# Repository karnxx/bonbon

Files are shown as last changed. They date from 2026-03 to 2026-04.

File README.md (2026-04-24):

# BONBON
### Animatronic from FNAF(Five Nights At Freddy's: Sister Localtion). This is basically a puppet of another animatronic, funtime freddy. so this animatronic features a 3dof head, eyes with eyelids, a mouth, and movable ears, 3 dof delta spine, 2 dof arms with 2 dof elbows, and the torso is indipendent, which means it can also move on its own. and the animatronic exos were taken from [@VomitedThoughts'](https://www.thingiverse.com/VomitedThoughts/designs) [BonBon Animatronic NHI](https://www.thingiverse.com/thing:7190069), huge thx to him! Eye mechs inspired from [Will Cogley's](https://www.youtube.com/@WillCogley) vid [How to Make a Compact Animatronic Eye Mechanism with 3D Printing and Arduino](https://www.youtube.com/watch?v=ihXxbQefl1c&list=WL&index=4&t=775s).

## [TUTORIAL](https://docs.google.com/presentation/d/1Cw9k8dLjZv4EjV3Pf7_rws1tL0UiAv238A7aoDvE18U/edit?usp=sharing)
- so i have a tutorial which is low qual but gets the job done.
- i will be making an assemble tutorial vid when i get the chance to make this.

## [BOM](https://docs.google.com/spreadsheets/d/1VHbBl1pK4IkEiJHbse9l7TyNy_vx4ArTAp4to9fVv3g/edit?usp=sharing)
- Google sheets, ive alr included the parts i have, and whats most convinient for me rn - the psu, u can use any power around 5-6v, with 13-15 amps.
  - 11 × SG90 → ~0.25A peak each → ~2.75A
  - 5 × MG90S → ~0.7A peak each → ~3.5A
  - 3 × MG995 → ~2.5A peak each → ~7.5A
  
 
    
## [CAD](https://gmail4855044.autodesk360.com/g/shares/SH90d2dQT28d5b602811fb614439d378a375)
- Cadded on fusion360, which is a great design tool. i also have included the timelapses of me designing bonbon in my journal.
- Ive also added clearances, and you do need inserts for this project.








## ELECTRICALS
- heres the wiring diagram
- im gonna be using an rpi pico for 16 of the servos, then the 3 mg995 ill be using a breadboard.
Untitled Diagram drawio

## CODE
- this is meant to be up to the user, so u can do wtver u want to. i reccomend using bottango or if u want u can rc it.

# NO AI WAS USED

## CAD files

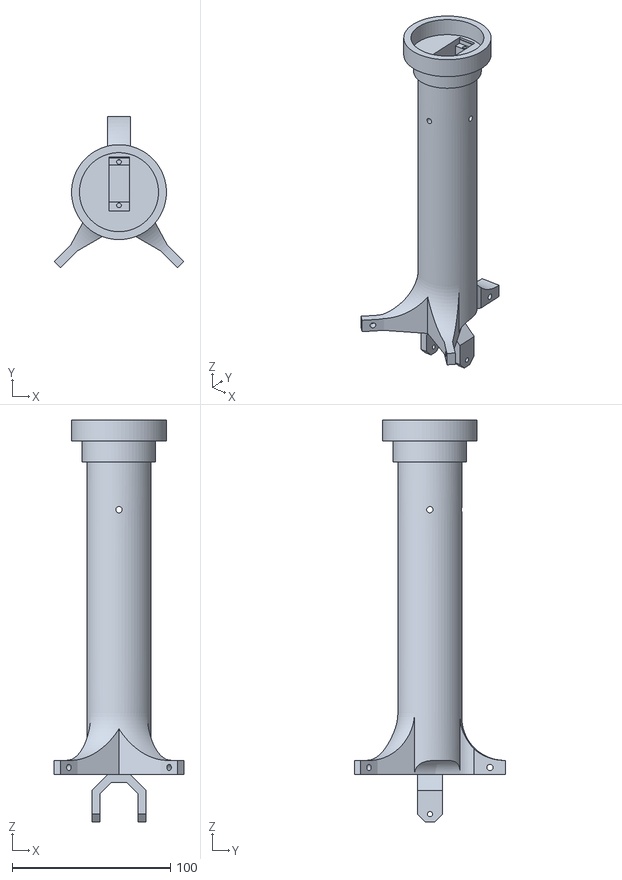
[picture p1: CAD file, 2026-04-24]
cad/printed parts/stls/1xspinewhole.stl
82.0 x 95.8 x 254.2

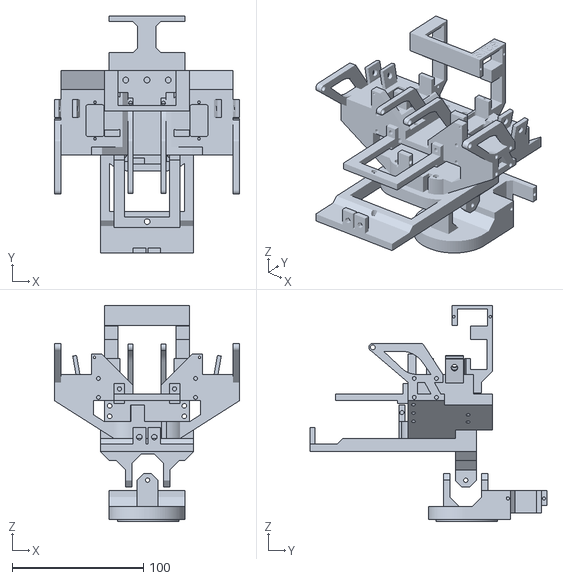
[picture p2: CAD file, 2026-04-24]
cad/printed parts/stls/1xhead.stl
141.1 x 180.6 x 164.6

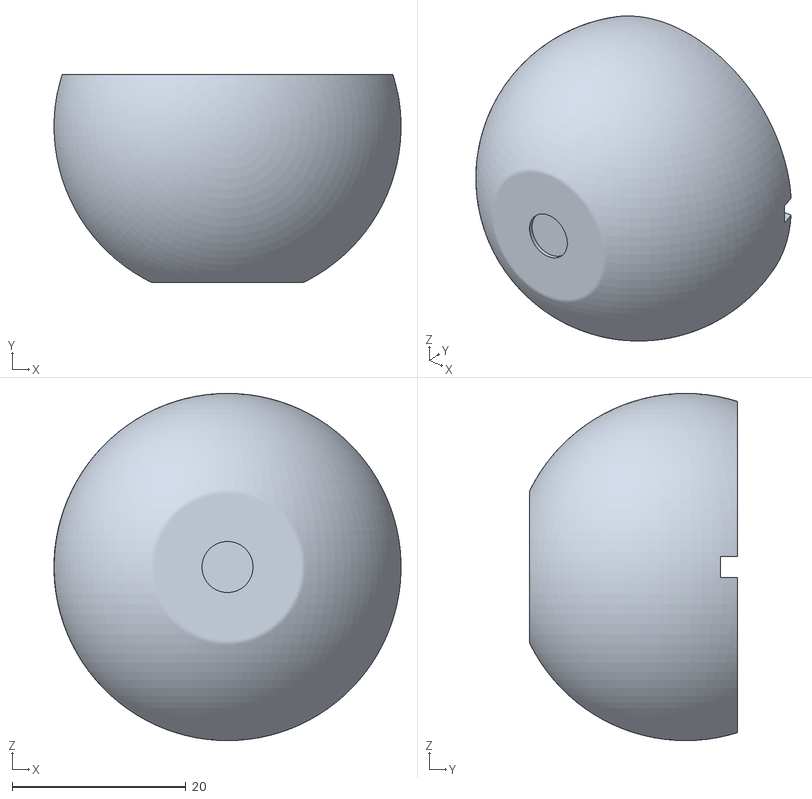
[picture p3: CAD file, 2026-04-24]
cad/printed parts/stls/2xeye.stl
40.0 x 24.0 x 40.0

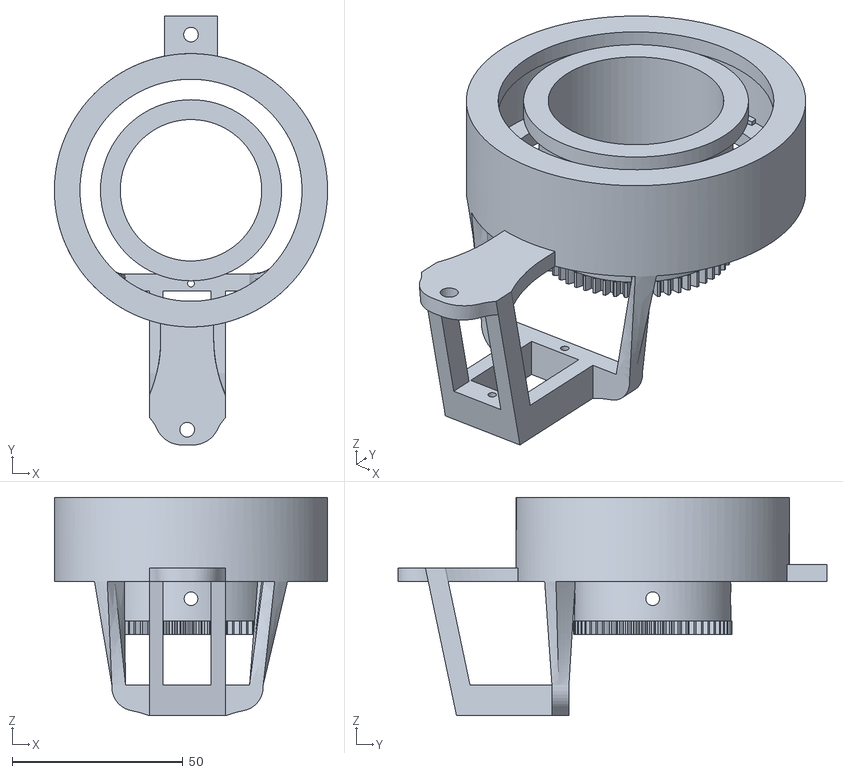
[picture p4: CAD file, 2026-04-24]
cad/printed parts/stls/1xspineconnectorandtorsotospine.stl
80.0 x 125.6 x 63.9

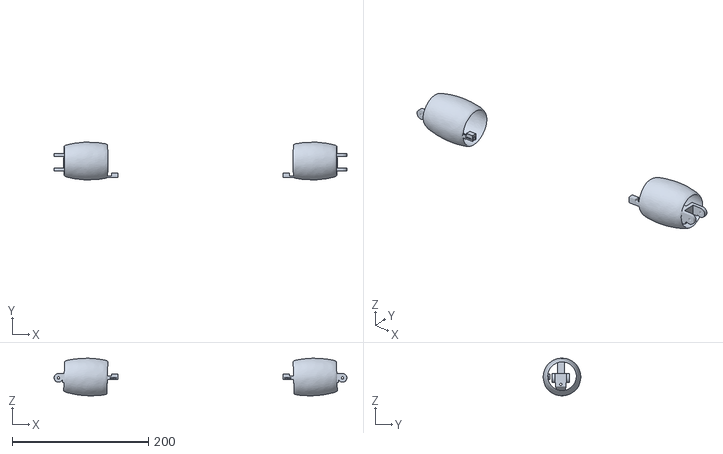
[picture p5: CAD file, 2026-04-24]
cad/printed parts/stls/1xbothforearms.stl
429.9 x 55.3 x 55.1

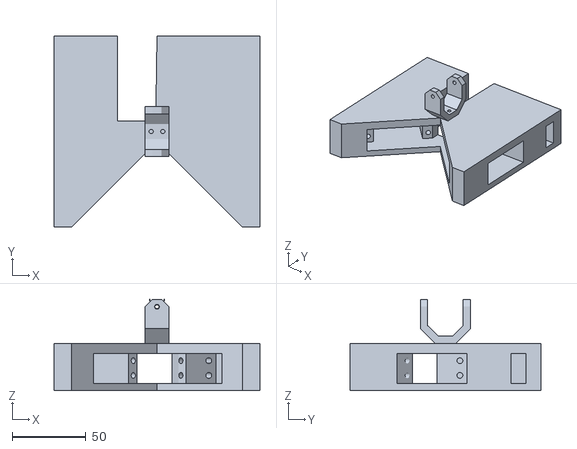
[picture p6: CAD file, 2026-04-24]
cad/printed parts/stls/1xspinebase.stl
140.0 x 130.0 x 62.1

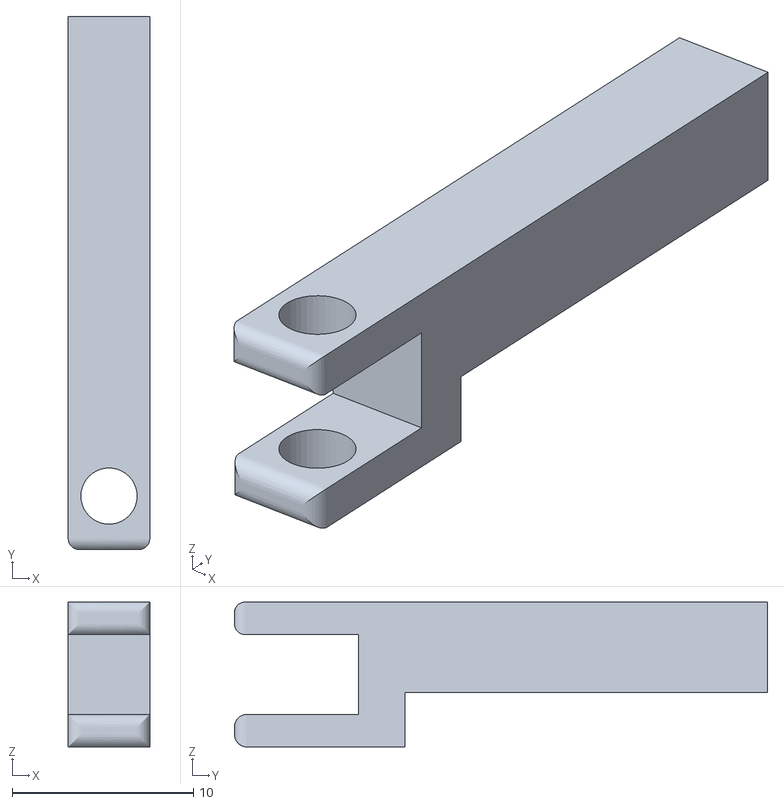
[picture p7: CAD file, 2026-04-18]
cad/printed parts/stls/2xanchoreye.stl
4.50 x 29.4 x 8.00

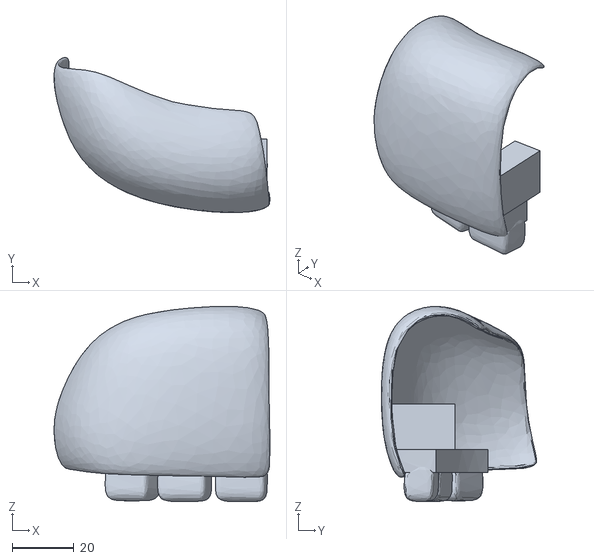
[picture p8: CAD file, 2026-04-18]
cad/printed parts/stls/1xsnoutr.stl
70.2 x 50.5 x 63.5

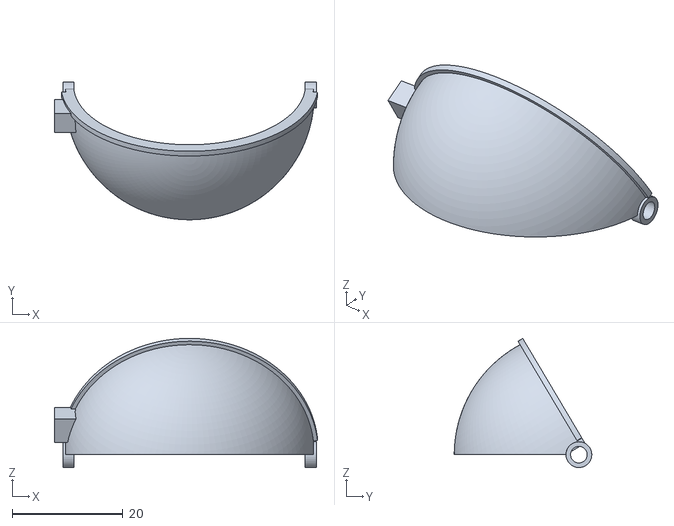
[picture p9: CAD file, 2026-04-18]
cad/printed parts/stls/1xdownlid1.stl
47.4 x 24.8 x 23.3

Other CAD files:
cad/printed parts/stps/shoulders.step
cad/printed parts/stps/forarms.step
cad/printed parts/stps/uptilttoadapter.step
cad/printed parts/stps/uplid1.step
cad/printed parts/stps/snoutl.step
cad/printed parts/stps/spinebase.step
cad/printed parts/stps/torso.step
cad/printed parts/stps/middlerotationpart.step
cad/printed parts/stps/downlidcontroller.step
cad/printed parts/stls/1xbothhands.stl
cad/printed parts/stls/1xbothshoulders.stl
cad/printed parts/stls/1xdownlid2.stl
cad/printed parts/stls/1xdownlidcontroller.stl
cad/printed parts/stls/1xjaw.stl
cad/printed parts/stls/1xjawshaft.stl
cad/printed parts/stls/1xskull.stl
cad/printed parts/stls/1xsnoutl.stl
cad/printed parts/stls/1xtorso.stl
cad/printed parts/stls/1xtorsogear.stl
cad/printed parts/stls/1xuplid1.stl
cad/printed parts/stls/1xuplid2.stl
cad/printed parts/stls/1xuplidcontroller.stl
cad/printed parts/stls/2xcardaninner.stl
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

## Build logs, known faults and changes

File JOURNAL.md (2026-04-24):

---
title: "Project BonBon"
author: "karnxx"
description: "i will attempt at making a bonbon animatronic."
created_at: "2026-3-21"
---

# March 20 2026: Started making the eyeball
- so today i started making the eyeball, since im gonna make the eye system, then the mouth and then ears, then neck and etc. the eyeball is pretty simple, its smtn like [this](https://youtube.com). so i have to custom design the eye and the adapter. this system is very effective, and compact. 

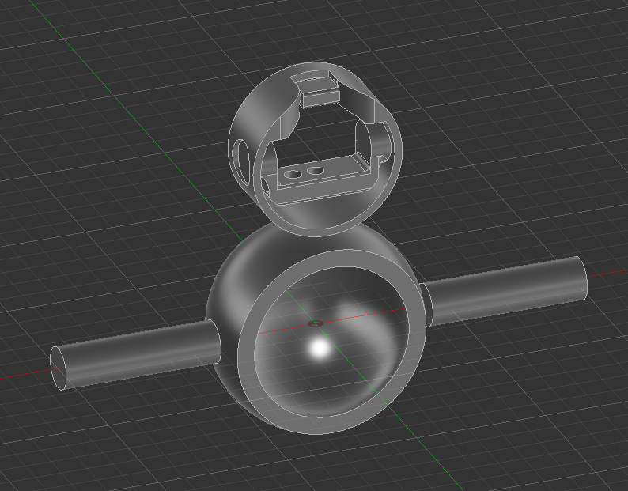
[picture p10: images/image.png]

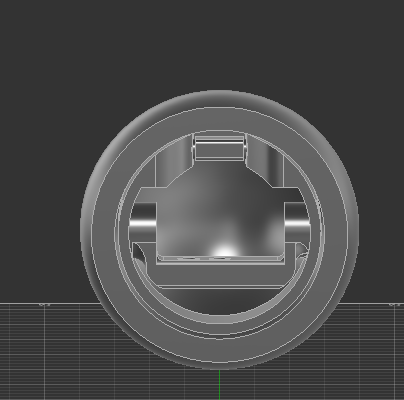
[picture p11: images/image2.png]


https://lapse.hackclub.com/timelapse/bPD6VYQ9OHWk \
https://lapse.hackclub.com/timelapse/R3avVUUkZ5Qu \
**Total time spent: 45 mins**

# March 21, 2026: Made eyeball snapfit.
- so i tried to make the eyeball snapfit. ill have to print them now. so ill print and then check the results.
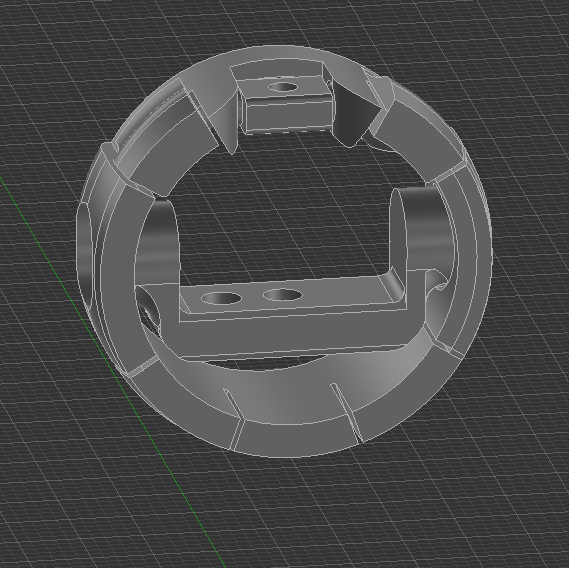
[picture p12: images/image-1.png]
 \
- after this ill ahve to make the main system, ill add joitns in fusion to make it more understandable.

### 9:43 pm

- so i made the things that go to servo. and i also made the fusion joint. i think ima have some problem with the fixed thng at the middle and the moving part right next to it, idk. and lol just as im writing this the print finished, lemme go check. so thrs alotta issues.. so first of all the up thingey is hard to get in, and the thing that supports it is very brittle. then the main adapter is hard to get in as well, and the other part in the adapter is very loose. im so bad at designing lol. ill fix these rn.
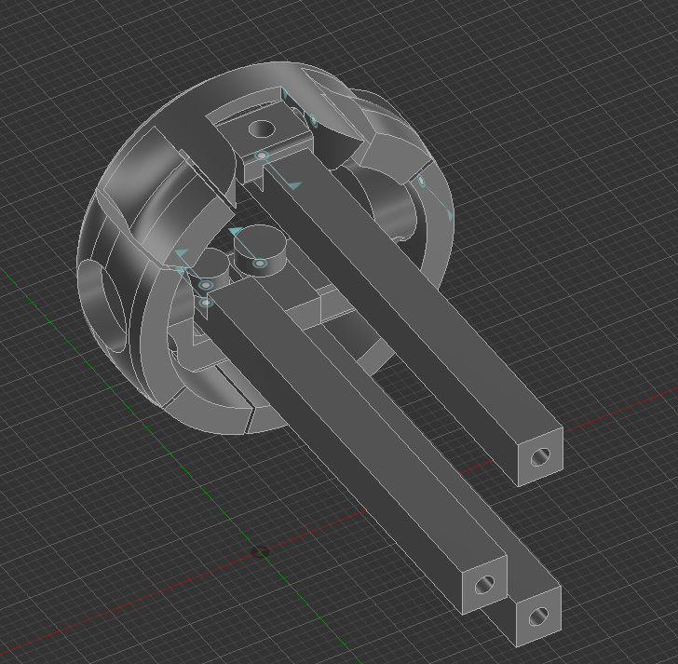
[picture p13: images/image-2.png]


https://lapse.hackclub.com/timelapse/Nn3NmJtqSQf6 \
https://lapse.hackclub.com/timelapse/R2DGub7P9Jni \
**Total time spent: 75 mins**

# March 22 2026: Remade the socket thing for eyeball
- the earlier design  didnt really work out, so i remade it and i printed a test.. which actually worked11!!
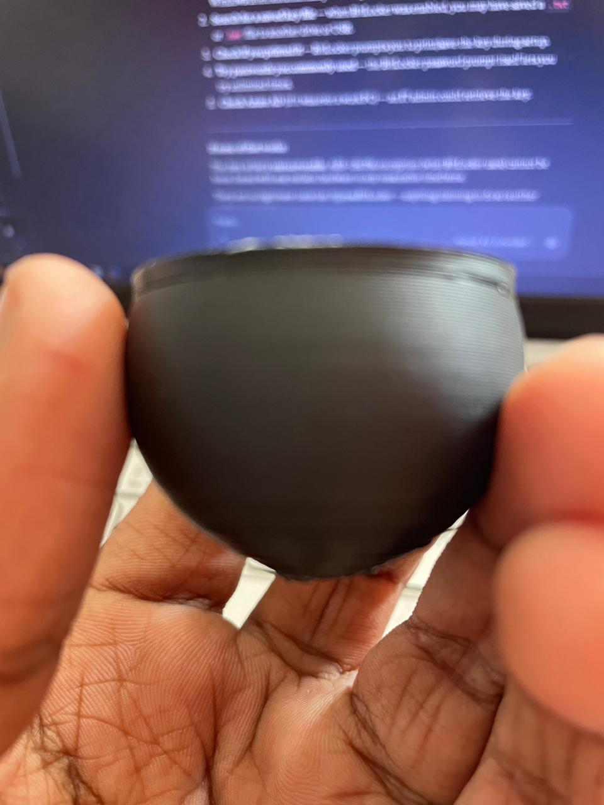
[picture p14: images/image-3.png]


- after that i designed so everything wud be able to fit on this. i also added this lip layer thing so that it wudnt be able to rotate freely in the sphere, and also added notches so it wudnt be rotating there. im gonna be super gluing this also, instead of relying on the joint. also addesd some space between the circle snap thing.

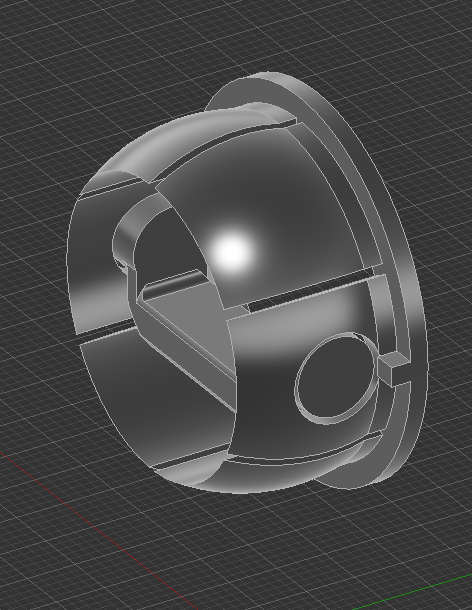
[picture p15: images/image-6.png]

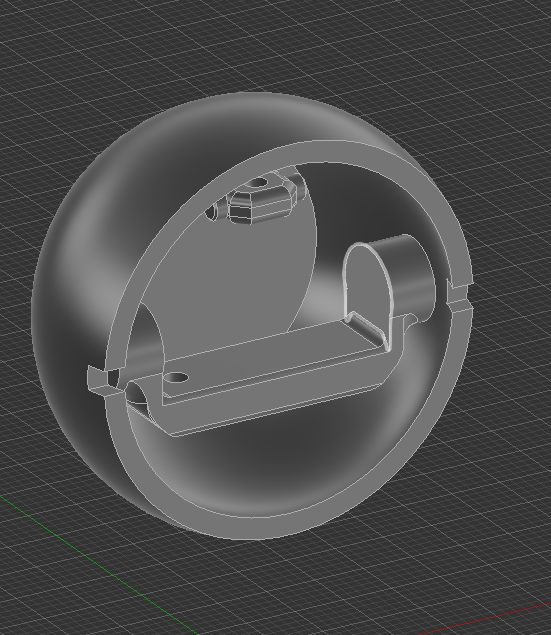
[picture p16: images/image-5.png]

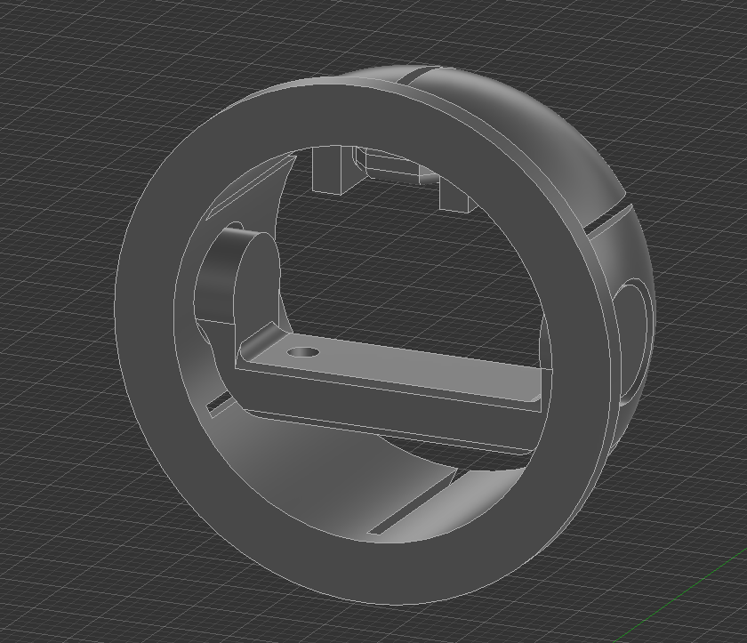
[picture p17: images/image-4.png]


- now ill set it to print and update the results here
- ok so it fits nice, and is easy to remove and all. then uhh themiddle part just needs to be sanded and the upper part is hard to put in, so ill have to fix that. shud be rlly quick, i dont think i need to record lapse.
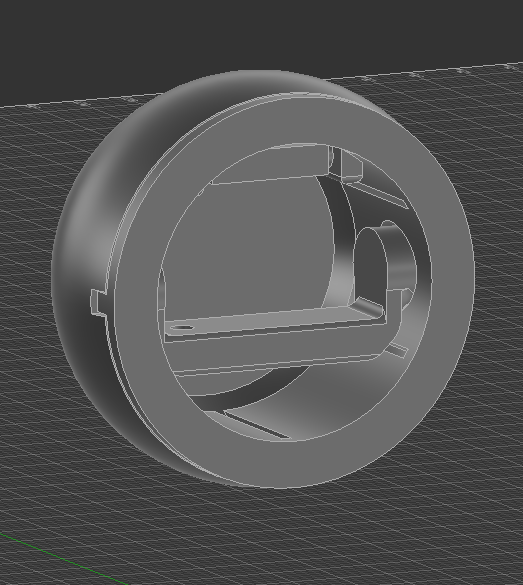
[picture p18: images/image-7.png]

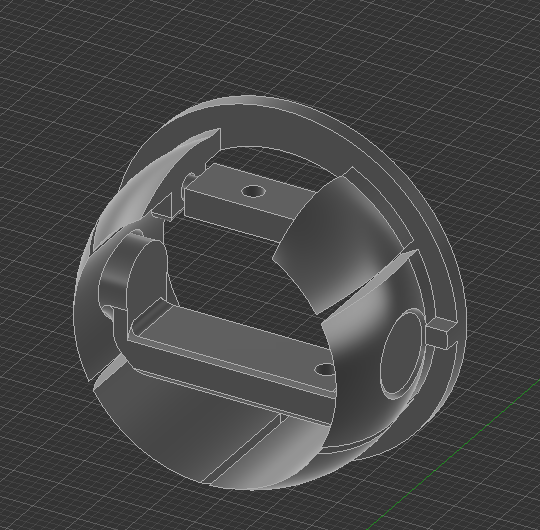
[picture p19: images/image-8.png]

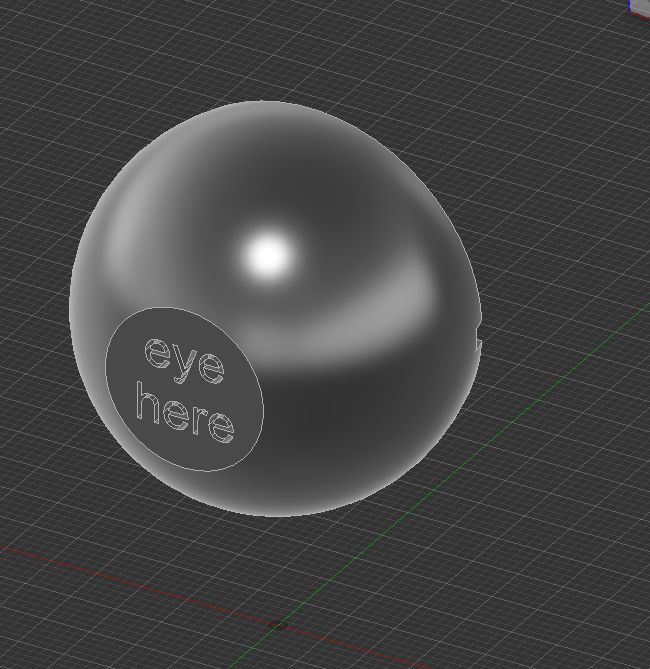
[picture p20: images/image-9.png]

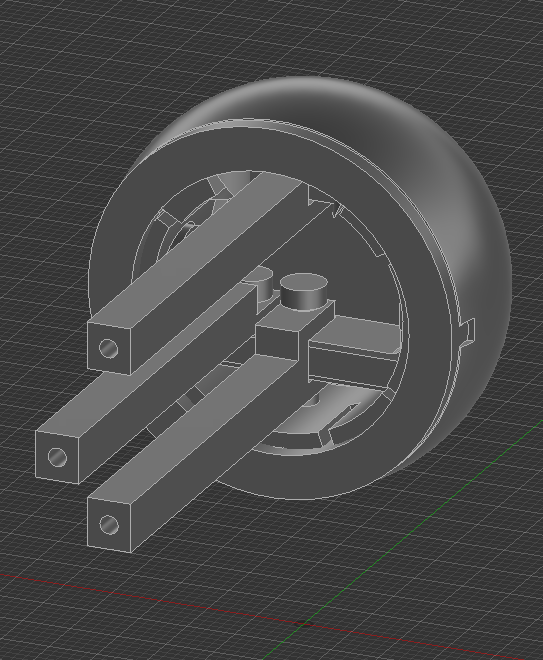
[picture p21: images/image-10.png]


- aight so i printed the new set and i think it came out rlly well. it just needs a bit sanding and a few more tweaks.

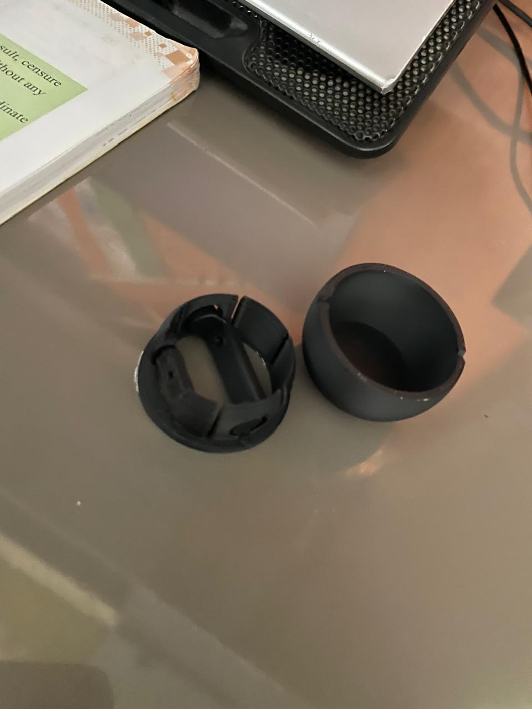
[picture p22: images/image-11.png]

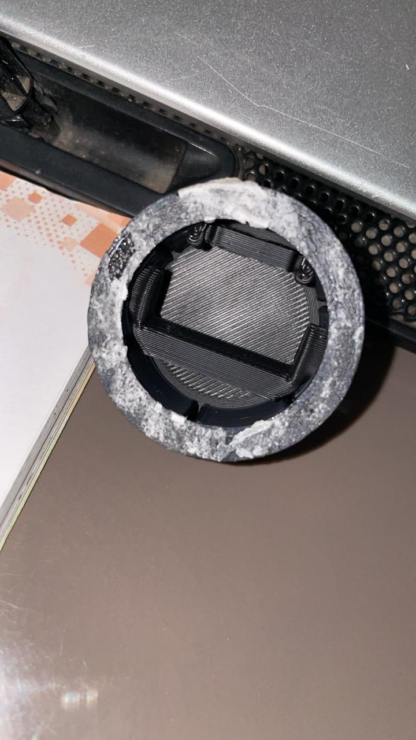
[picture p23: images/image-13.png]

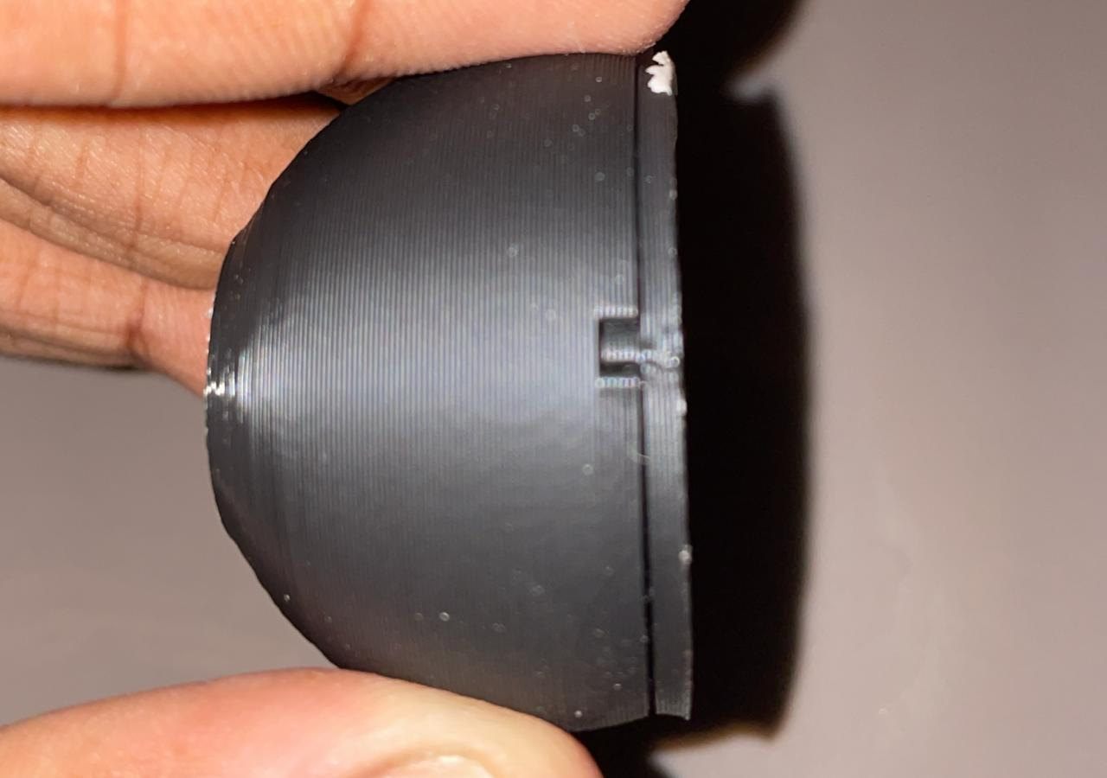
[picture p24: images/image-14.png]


https://lapse.hackclub.com/timelapse/miGNqXrjUI7L \
https://lapse.hackclub.com/timelapse/nTVNja44oHZ4 \
**Total time spent: 30 mins**

# March 23 2026: made eyelids and the main housing.
- today i made the eyelids. they follow a rlly simple system. as you can see, the top eyelids will be controlled by 1 servo while the other two by another. so they connect togehter in the middle area
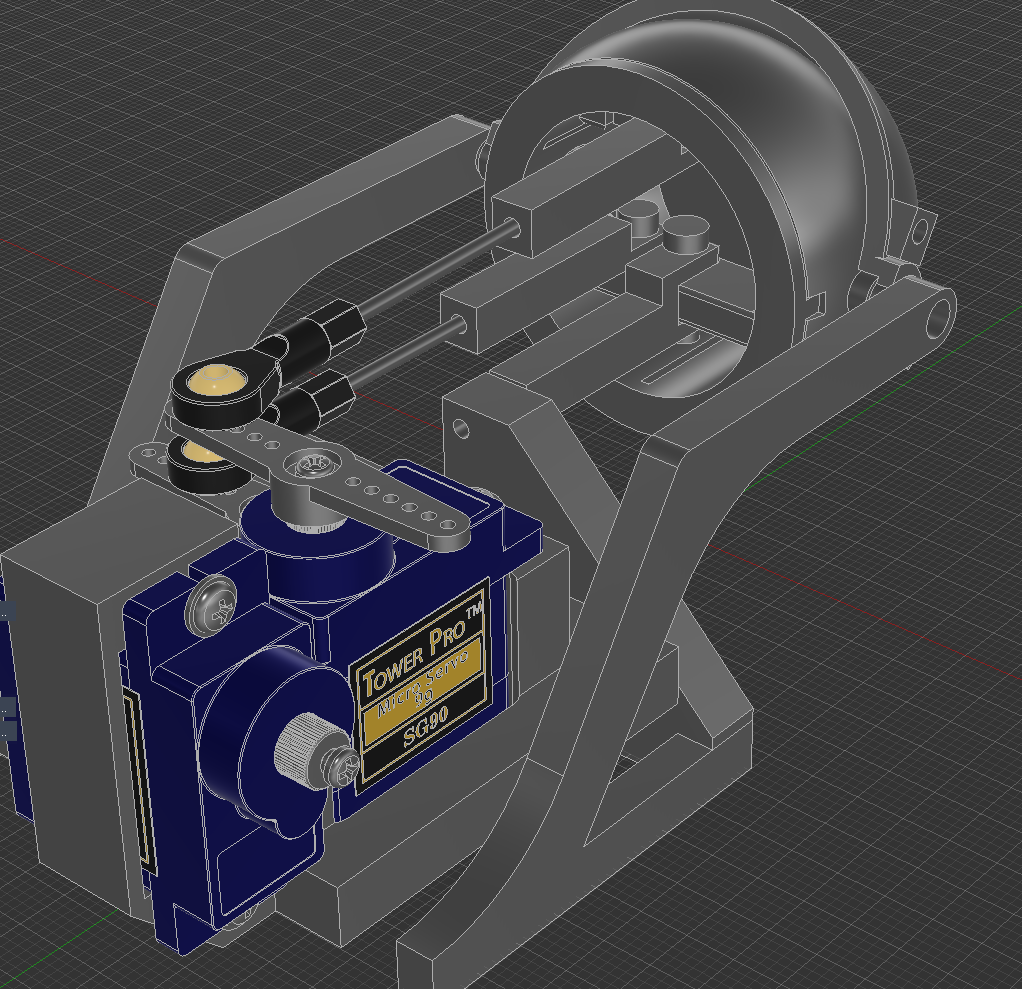
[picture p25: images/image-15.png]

(right eye btw)

- so tmrw ill just mirror this, set appropriate distance between these individual eye system, and like myabe ill be finished by tmrw. heres the whole thing btw

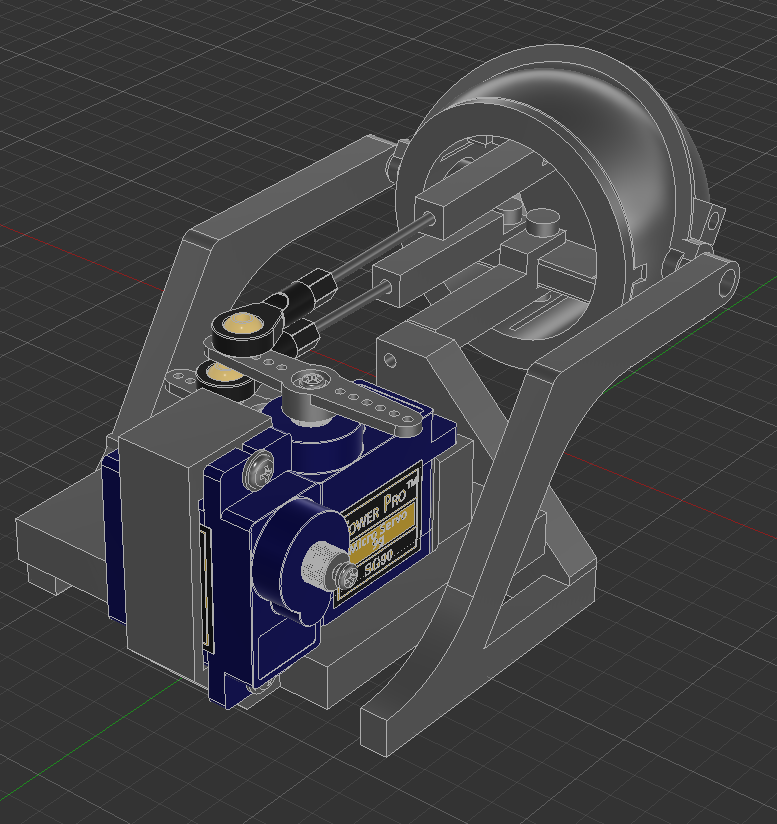
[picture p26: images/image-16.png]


- oh yeh, im also gonna be using ball link joint to make it more versatile. also using sg90 servos

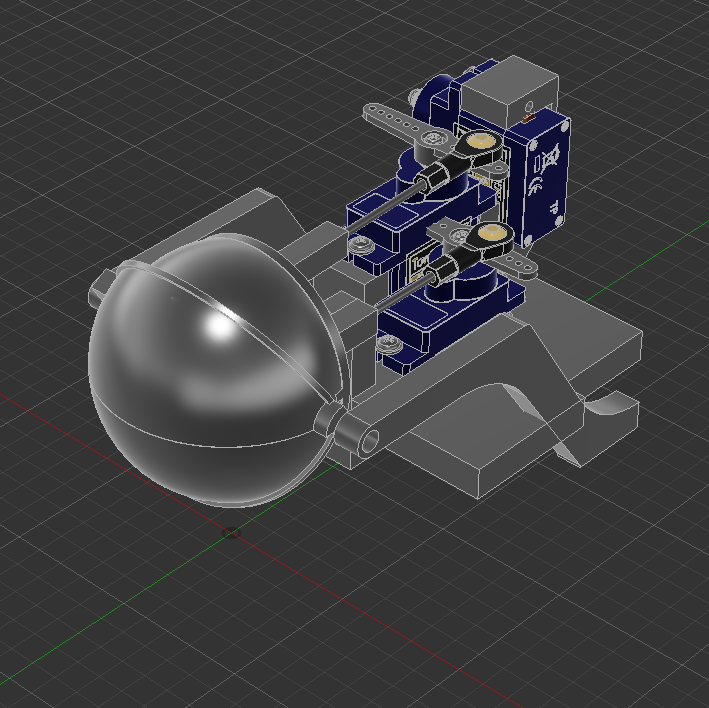
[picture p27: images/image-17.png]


- well my confidence is kinda low, idk if ill be able to finish this prj. 

https://lapse.hackclub.com/timelapse/-Gv8fdGwFlrq \
**Total time spent: 90 mins**

# March 24 2026: made both eyes and eyelid system, mouth and ear systems started.
- so today  i made both the eyes, and the 2 servos for the eyelids. then for the mouth system, im gonna use thread tied to a servo, which is tied to the mouth. its a simple mechanism, and less part of the mechanism is seen. then for the ears, i wanted to hve the same kinda system but im kinda lost. if i were to tie threads, then there wud be no way of getting the ears to stand upright again. so maybe i will have to directly connect the servo to it or ihave another idea, that we can make the ear rotate around a hinge/pivot so that i can rotate with servo and like the ear has 2 parts, the base and the top, so the top will also be in a hinge with the base, ad the base to the head, and like yeah thats it.
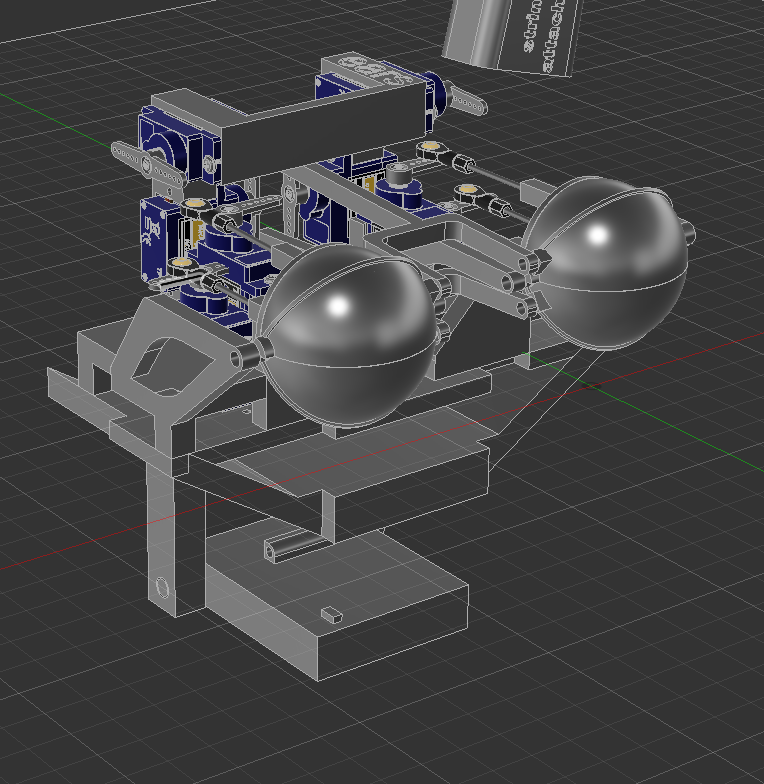
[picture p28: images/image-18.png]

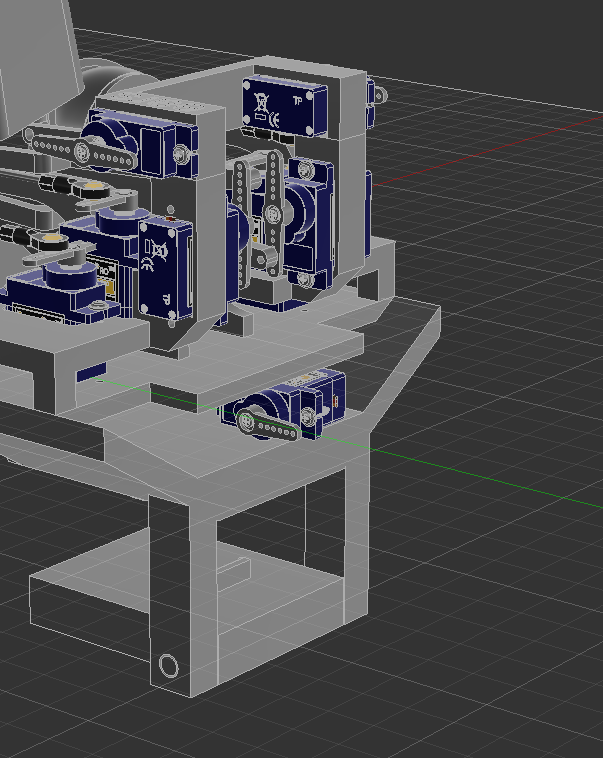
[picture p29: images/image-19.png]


- thr will be a compartment under the eye system to have another servo in, which controls the mouth.  and above the eyelid servos will be the ear servos.

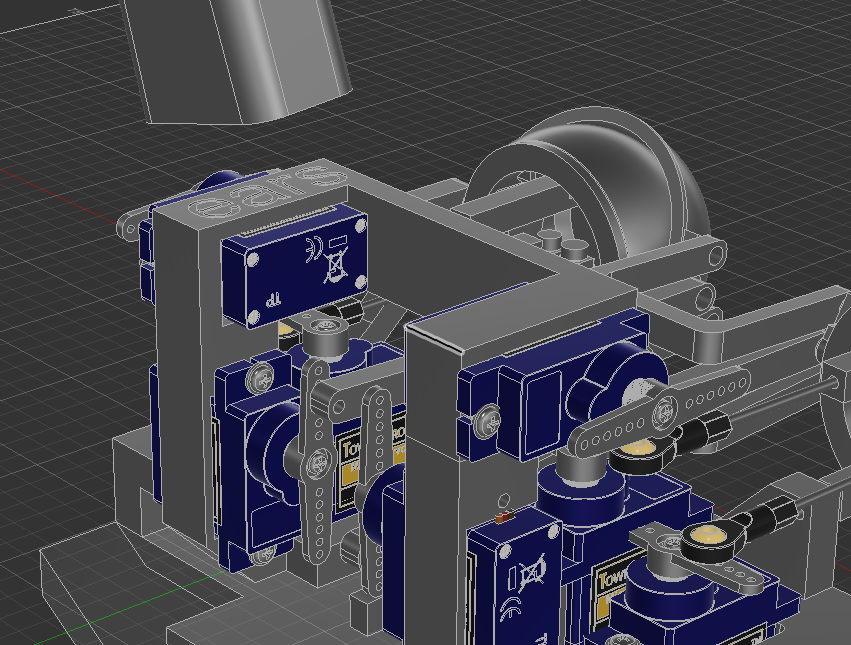
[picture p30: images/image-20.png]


https://lapse.hackclub.com/timelapse/Znfbiogx-C5f \
https://lapse.hackclub.com/timelapse/NDLfO3voyw2G \
**Total time spent: 80 mins**

# March 25 2026: ear system
- so like the ear system is simple, the ear is gonna have a pivot to rotate on, and the servo will like rotate to rotate the ears. maybe ill make it so that the other side of the servo controls the upper part of the ear, so like when it goes towards the eye, theear will curl and vice versa.

- but more importantly, the neck system. i have 2 different ideas for now.
- first that we use mechanic that eyes use. so like there will be a cross type thing, 2 servos control like the side and bring it down and all, ykwhat it wud be easier to explain with an img.
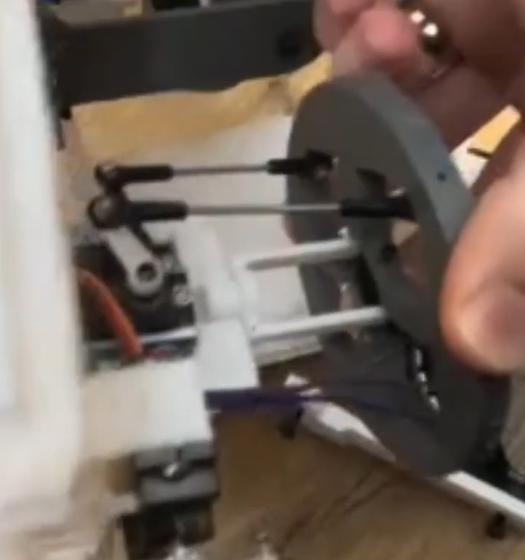
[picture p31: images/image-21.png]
 by smith robotics btw \
-or we use this system, where 2 servos control side to side and another for tilt, but it wud put strain on the servos, so like shi.
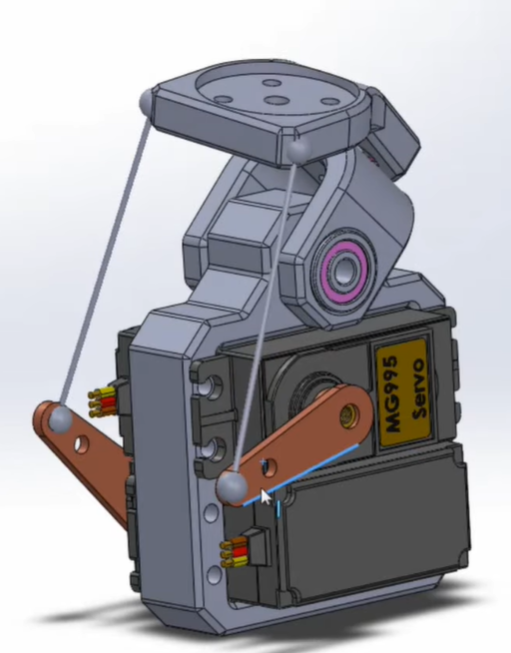
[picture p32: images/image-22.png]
 by foxlabs 
- orr smtn like this
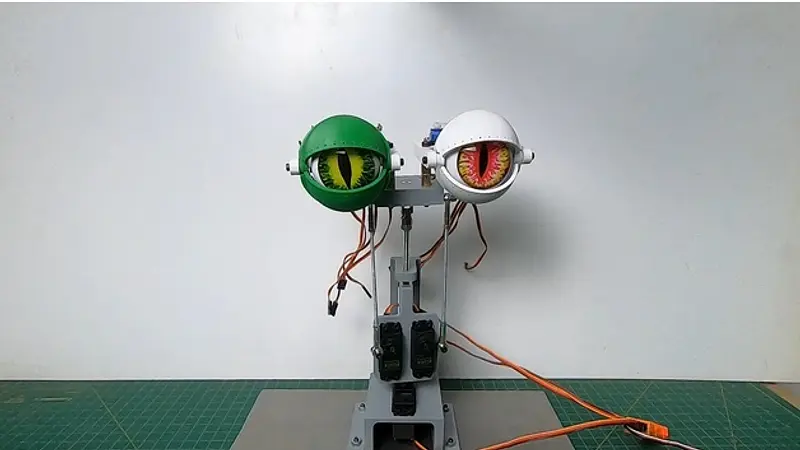
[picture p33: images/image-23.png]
 by hendrikxworkshop
- or we cud use pneumatics or linear actuators, but cost would be too much...

aight i think ima go with the 2nd one. 
https://lapse.hackclub.com/timelapse/CyRsjBEQdOK- \
(btw i synced the wrong project from lapse to my hackatime prj) \
**Total time spent: 23 mins**

# March 30 2026: neckk
- omfg this was so hard. so there were problems with the earlier design type i wanted to choose, namely too much stress on the servos. so i decided to make like a different type of neck thing. so i thought of many which took me alotta days.
- so today i thought of this design, using a cardan joint:

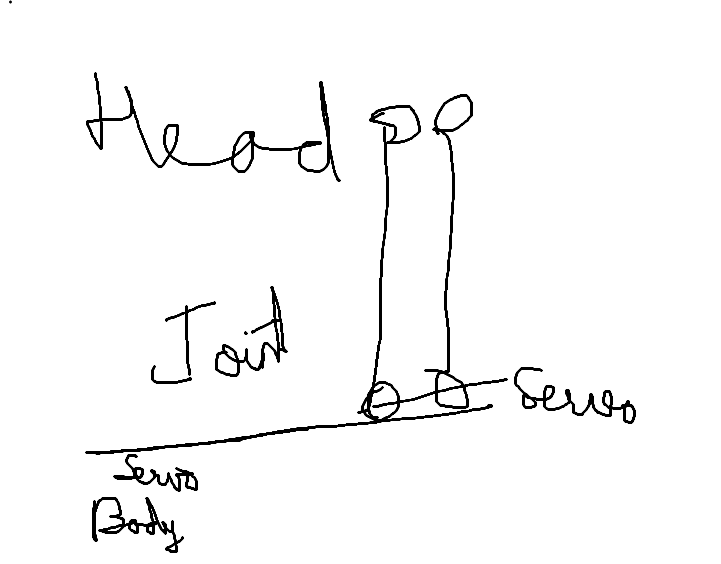
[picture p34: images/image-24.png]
 \
(ikik im the best at drawing)

- so this would remove the stress, and ike concentrate it to the rotational. but then i saw [this](https://www.youtube.com/watch?v=a3hMkZzgGIY) one yt vid, whr they had the same problem, and they used a normal servo, but concentrated the weight on the bearings instead, which was perfect for my use. and about the ear, thrs just gonna be a string which needs to go through the ear hole thing. yeah for now its looking quite good, but its gonna get a lot more compicated now. ok so now we have to make the body with the hands. this animatronic doesnt have legs, instead its gonna be stuck to the ground and has like a backbone type thing which is controlled by 3 servos at the base. and i havent done any research about the arm so yeah. (my confidence is decreasing againn..)
- anyways heres the bot:

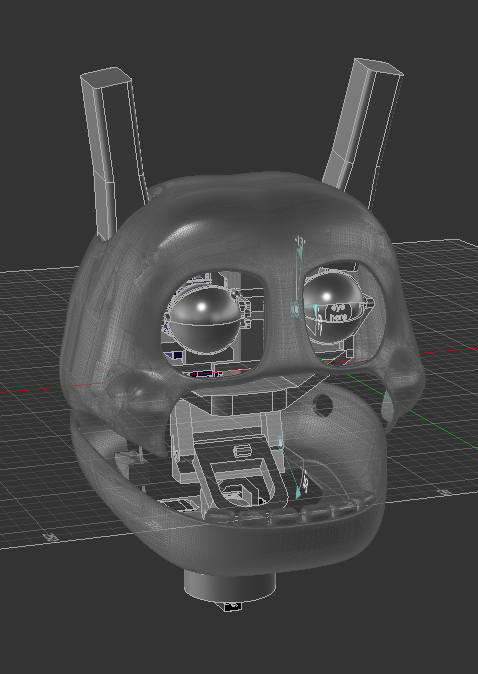
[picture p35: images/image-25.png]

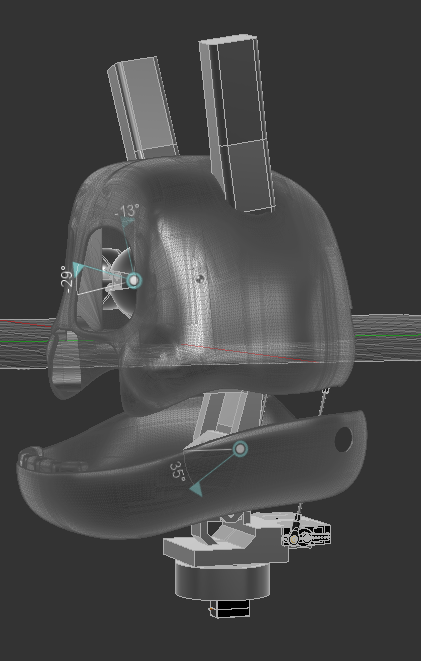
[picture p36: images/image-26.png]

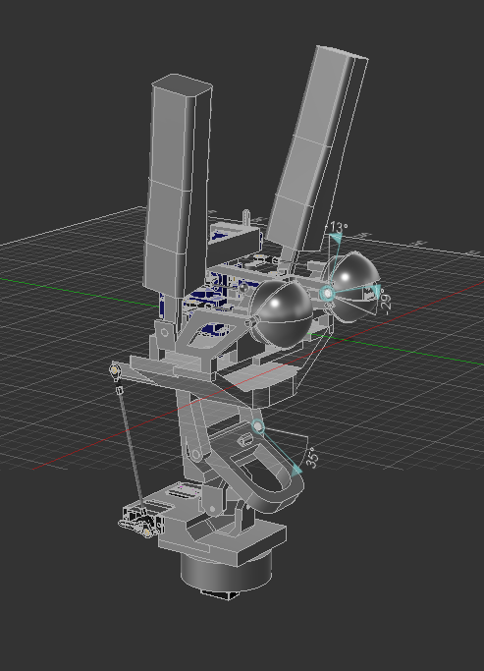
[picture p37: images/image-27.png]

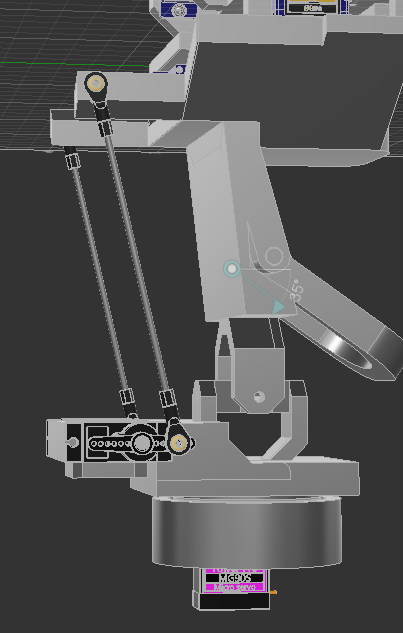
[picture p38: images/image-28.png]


https://lapse.hackclub.com/timelapse/1hOzd2pi9AwY \
**Total time spent: 60 mins**

# April 2 2026: redesign mouth and neck
- aight so, i had do scrap the endo mouth idea.. this was mainly because the space between the lower jaw and the torso was too much. anyways, it looks much better now, and for the torso, im gonna make it so that it can spin around the spine, and i also scrapped the organic spine since its not required. after that, the entire spine will be controlled by 3 servos in a delta movement type. so the servo wil be attached to the spine via a 6009 bearing, where id is 45mm. and then our servo will be having gear and the spine willalso have a gear. then yeah rotating torso. here are some images:

- before: \
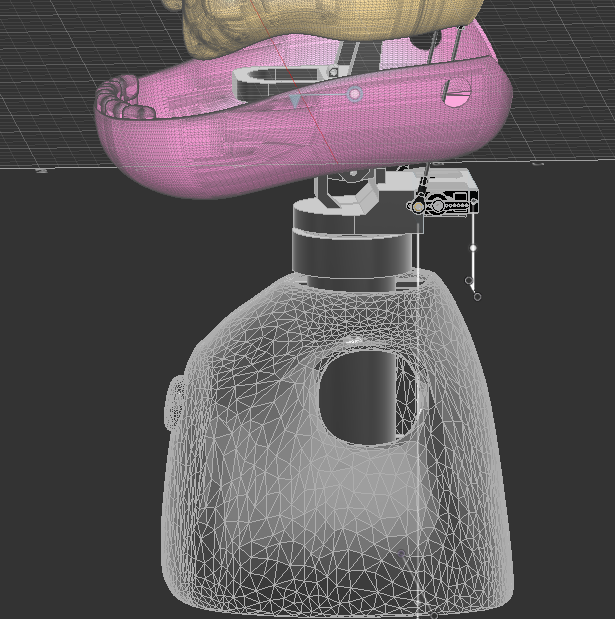
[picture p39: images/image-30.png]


- after: \


- it looks alot cleaner now. aight so for tmrw, i have to find a way to make the bearings get mounted on the shaft, to install bearings on the torso, i havent decided yet whether to directly, pause print then put the bearing and resume print or to make another part which will require bolts to mount to the torso.. or i could print the spine in 2, slide bearing and yeah, orr i could pause print and install the bearing directly on spine, but then that would be bbad for mounting. i havent rlly added alot of screws and all to the 3d model, i was thinking to do tht at the end.

https://lapse.hackclub.com/timelapse/krj9sUdxkGHx \
**Total time spent: 60 mins**

# April 3 2026: torso movement
- my plan for the torso it that it can rotate itself too. so like what i did today, is that i first made a mount for the bearing, 6009, so that it can go on the spine. so like this will be print in place, so ill have to put the bearing while print is paused. then these extend to 2 rectangular things tht the torso will be on, and a scre will be thr preferably either m4 or m5. then for the servo, i had a gear ratio of servo to the spine of about 15:28, so its still gonna be slower. anyways the bearing is paused print and will contains holes on the mountso that it can be screwed in. at the end my fusion crashed and i gave up lol, it was very slow. 


 

https://lapse.hackclub.com/timelapse/cSkal16kF115 \
**Total time spent: 55 mins**

# April 5 2026: ARMS!
- aight so i finished the arms in 1 day lol. basically the arm consists of 2 joints, shoulder and elbow. both 2 dof. ive done the shoulder joint my implementation of what i understood of this: \
 \
[from here](https://www.youtube.com/shorts/eS1hgH4-Uzs)
- so like 1 servo rotates the arm, and 1 controls the tilt, very simple, while also limiting the movement because the tilt is based on the freedom of rotation ball links that connect them together. the tilt also depends on the length of the rod between the ball links. then the elbow joint is also pretty simple, consisting of 2 servos, and yeah this image should explain it. if not then watch this (vid)[https://www.youtube.com/watch?v=xflvEGV2g5A], its rlly good about simple animatronics. \
 \
- this huge progress was because i had an exam and thus i was preparing for it, leaving me with no time to work on this. after this i just have the spine movement and then were done! acc were not, because i have to make the screw holes and ill try to find a way to make the eyes bigger. heres how it looks like:
  \
(ignore the ears, ill swap them for better ones) \ 
 \
 \
- btw ive been using (this bonbon animatronic by VomitedThoughts)[https://www.thingiverse.com/thing:7190069] for the exoskeleton.
- and for the hand, i may add a servo in the torso which will have strings to the hand. but i think thts too excess yk.

https://lapse.hackclub.com/timelapse/9guGHKM7eV-Y \
https://lapse.hackclub.com/timelapse/gGWLU0hz1oCb \
**Total time spent: 98 mins**

# April 7 2026: The End
- ALR so the cad process is over.
- i did this all in one log bcuz i forgot to do other days logs, alr lemme explain the things i did 1by1
- first i made the ears, the ears will be conecnted a servo inside the head, which also has a string. then the top part of the ear can tilt front and back. so liek good ears ig. also to attach the rod thing to the ear i make the slot a lil bigger and also will use super glue/hot glue. so heres some pics of the ear. 




- after that i made the spine which follows a delta-type movement. heres some pics. here ive switched from typical servos to a MG996R, which is required for the immense pressure. also theres another cardan joint here, which will be printed in high infill.




- so i decided to ditch the eyes making bigger and made this my own adaptation of bonbon. 



- after that i cut the main head into many pieces so that it wud be easy to print, with less overhangs. 



- then for the nose, i extruded some part of the main head, and made a moutn for the nose. 



- for the head, i removed the existing mounts and added my own mounts to go with my bonbons head.



- after that for the lower jaw, i made kind of a pivot thing taht connects to the main head. the jaw is controlled by servo by string.




https://lapse.hackclub.com/timelapse/ITjfcc8l0LcY \
https://lapse.hackclub.com/timelapse/vf3MrfMEJtNR \
**Total time spent: 305 mins**

# April 15 2026: (not rlly)The End
- so ive ordered the parts, mainly the ball links and the m2 threadded rods. im gonna make a prototype of the eyes b4 moving on to the rest. ive also made the bom, which tells u which parts to buy. i alr have the rpi pico, and the 16 channel servo controller. https://docs.google.com/spreadsheets/d/1VHbBl1pK4IkEiJHbse9l7TyNy_vx4ArTAp4to9fVv3g/edit?usp=sharing.
**Total time spent: 40 mins**

# April 24 2026: END
- aight so like ive made a tutorial, which is like low qual-ish but it gets the job done. ive also fixed some parts, added tolerances and all as well. this took ALOTTA time, as fusion stopped working in my laptop, so i had to use web, and i cudnt get the stp or other file, it gets sent to my gmail. i didnt rec with lapse tho this time.
**Total time spent: 300 mins**
